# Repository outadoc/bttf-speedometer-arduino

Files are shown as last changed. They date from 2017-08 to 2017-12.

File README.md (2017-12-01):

Arduino-based Back to the Future DeLorean Speedometer
=====================================================

Finished prototype
------------------
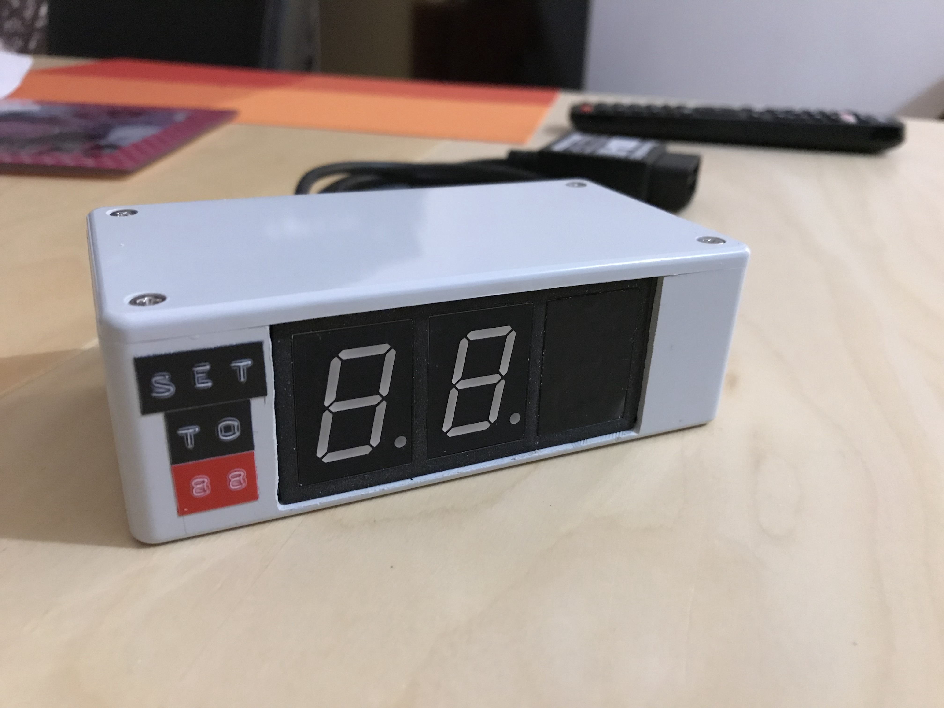
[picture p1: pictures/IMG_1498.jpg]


License
-------
    Copyright (C) 2017  Baptiste Candellier

    This program is free software: you can redistribute it and/or modify
    it under the terms of the GNU General Public License as published by
    the Free Software Foundation, either version 3 of the License, or
    (at your option) any later version.

    This program is distributed in the hope that it will be useful,
    but WITHOUT ANY WARRANTY; without even the implied warranty of
    MERCHANTABILITY or FITNESS FOR A PARTICULAR PURPOSE.  See the
    GNU General Public License for more details.

    You should have received a copy of the GNU General Public License
    along with this program.  If not, see <https://www.gnu.org/licenses/>.

Components
----------

| Part | Qty  | Manufacturer | Reference |
|---|---|---|---|
| OBD-II UART Adapter V2 | x1 | Freematics | OBD-U |
| Microcontroller | x1 | Arduino | Arduino Nano |
| Enclosure | x1 | Hammond | 1591C |
| 7-segment display | x3 | Multicomp | LS0803SRWK |
| Potentiometer | x1 | Vishay | 3296W-1-203LF |
| Slide switch | x1 | C&K | OS102011MA1QN1 |
| Slide switch | x1 | Knitter-Switch | MFS131D |
| Resistor (165 Ω) | x8 | Vishay | MRS25000C1650FCT00 |
| 16-pin board-to-board conn. | x2 | AMP | 6-534237-4 |
| DB25 male connector | x1 | FCI | DB25S064TLF |
| DB25 female connector + shell | x1 | MH | MHDTPPK-25 | 
| 10-pin wire-to-board housing  | x1 | Molex | 22-01-2105 |
| 5-pin wire-to-board housing | x1 | Molex | 22-01-2055 |
| 10-pin wire-to-board header | x1 | Molex | 22-27-2101 |
| 5-pin wire-to-board header | x1 | Molex | 22-27-2051 |
| Crimp terminal | many | Molex | 0008500113 |
| Labels | x3 | Dymo | Omega |

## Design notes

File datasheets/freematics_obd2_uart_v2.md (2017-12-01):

# Freematics OBD-II UART Adapter V2 (for Arduino)

This product works as a data bridge between a car's OBD-II port and Arduino with dedicated Arduino library provided. It provides fast OBD-II data access, as well as 6-axis MEMS motion sensor module and voltmeter for measuring car battery voltage. The adapter draws power from OBD-II port and convert it to 5V (up to 2.1A) for powering itself and attached device (Arduino board, shield or other components). 

## Features

- Access to all standard OBD-II PIDs with extended ELM327 AT command-set
- Reading and clearing vehicle diagnostic trouble codes (engine & powertrain only)
- Measuring car battery voltage
- Built-in MPU-6050 6-DOF motion sensor (accelerometer, gyroscope & temperature)
- Supplying power for host device (5V up to 2.1A)
- Serial UART data interface compatible with both 3.3V and 5V micro-controllers
- Micro USB port for computer/tablet OBD-II access and firmware upgrade
- Arduino library and example sketches available
- Low power mode @6mA

## Compatibility

The adapter plugs into the OBD port usually located under the steering column or slightly to the left of it. To check if your vehicle is OBD-II certified, open your hood and find the sticker that looks like this:

Vehicles using following vehicle protocols are supported.

- CAN 500Kbps/29bit
- CAN 500Kbps/11bit
- CAN 250Kbps/29bit
- CAN 250Kbps/11bit
- KWP2000 Fast
- KWP2000 5Kbps
- ISO9141-2

The OBD-II Adapter is compatible with all Arduino range including Arduino UNO, Arduino Leonardo, Arduino Micro, Arduino Nano, Arduino Mini, Arduino Pro Mini, Arduino MEGA 1280/2560/ADK.

## Connectors

The adapter stays plugged into the OBD port usually located under the steering column or slightly to the left of it.  A cable comes out from the adapter and splits into one 4-pin connector two 2-pin connectors, including power lines (VCC/GND) and data lines (Rx/Tx). They can be connected to Arduino with onboard breakout pins or breakout shield. Your Arduino device will look tidy in car with only one cable.

Power Connector (2-pin 2.54 Dupont connector)

- Red: VCC (connecting to Arduino’s VCC)
- Black: GND (connecting to Arduino’s GND)

Serial UART Data Connector (2-pin 2.54 Dupont connector)

- White: Rx (connected to Arduino’s serial Tx)
- Green: Tx (connected to Arduino’s serial Rx)

USB Port

- For connection with computer or tablet via micro USB cable
- For power output (5V/2A)

## Extended ELM327 Command Set

We have extended standard ELM327 command set for following purposes:

- Multiple (up to 8) OBD-II PIDs reading from a single query
- Accessing built-in MEMS module (MPU-6050)
- Accessing built-in voltmeter (measuring battery voltage)

Following are the added commands:

### ATACL

- Function: reading accelerometer data
- Response: X/Y/Z values from accelerometer in format of X,Y,Z

### ATGYRO

- Function: reading gyroscope data
- Response: X/Y/Z values in the format X,Y,Z

### ATTEMP

- Function: reading temperature data
- Response: temperature (raw) data

### ATRV

- Function: reading car battery voltage
- Response: voltage value

The Arduino library has API implemented with all the extended commands.

## Library

A dedicated Arduino library is provided for easy access to all the features with any type of Arduino.

Some commonly used APIs are like following:

- setBaudRate - set adapter serial baudrate
- readPID - read specified OBD-II PID and return parsed value
- clearDTC - clear diagnostic trouble code
- getVoltage - measure car battery voltage
- getVIN - retrieve Vehicle Identification Number
- getTemperature - get device temperature
- readAccel - read accelerometer X/Y/Z values
- readGyro - read gyroscope X/Y/Z values

There are more extensive APIs experts. Please refer to the library header file for more information.

Here is an example Arduino sketch of a simplest engine RPM indicator, which uses the pin 13 LED (built in on Arduino board) to indicate whether the engine is above 3000 rpm.

```cpp
#include <OBD2UART.h>

COBD obd;

void setup()
{
  // we'll use the debug LED as output
  pinMode(13, OUTPUT);
  // start communication with OBD-II adapter
  obd.begin();
  // initiate OBD-II connection until success
  while (!obd.init());
}

void loop()
{
  int value;
  // save engine RPM in variable 'value', return true on success
  if (obd.readPID(PID_RPM, value)) {
    // light on LED on Arduino board when the RPM exceeds 3000
    digitalWrite(13, value > 3000 ? HIGH : LOW);
  }
}
```

A more comprehensive example sketch can be found here.

Some commonly used PIDs are defined in OBD library as following.

### Engine

- PID_RPM – Engine RPM (rpm)
- PID_ENGINE_LOAD – Calculated engine load (%)
- PID_COOLANT_TEMP – Engine coolant temperature (°C)
- PID_ENGINE_LOAD – Calculated Engine load (%)
- PID_ABSOLUTE_ENGINE_LOAD – Absolute Engine load (%)
- PID_TIMING_ADVANCE – Ignition timing advance (°)
- PID_ENGINE_OIL_TEMP – Engine oil temperature (°C)
- PID_ENGINE_TORQUE_PERCENTAGE – Engine torque percentage (%)
- PID_ENGINE_REF_TORQUE – Engine reference torque (Nm)

### Intake/Exhaust

- PID_INTAKE_TEMP – Intake temperature (°C)
- PID_INTAKE_PRESSURE – Intake manifold absolute pressure (kPa)
- PID_MAF_FLOW – MAF flow pressure (grams/s)
- PID_BAROMETRIC – Barometric pressure (kPa)

### Speed/Time

- PID_SPEED – Vehicle speed (km/h)
- PID_RUNTIME – Engine running time (second)
- PID_DISTANCE – Vehicle running distance (km)

### Driver

- PID_THROTTLE – Throttle position (%)
- PID_AMBIENT_TEMP – Ambient temperature (°C)

### Electric Systems

- PID_CONTROL_MODULE_VOLTAGE – vehicle control module voltage (V)
- PID_HYBRID_BATTERY_PERCENTAGE – Hybrid battery pack remaining life (%)

Additional defines can be added to access all OBD-II PIDs which the car’s ECU provides.

## Comparison

The following table lists the differences among different Freematics OBD-II adapter models.

| Features \ Models | OBD-II I2C Adapter | OBD-II UART Adapter V1 | OBD-II UART Adapter V2 |
|---|---|---|---|
| Connection Interface | I2C | Serial UART | Serial UART |
| Additional Interface | N/A | N/A | microUSB |
| MEMS Sensor | MPU-6050 | N/A | MPU-6050 |
| Voltmeter | Yes | Yes | Yes |
| Max. Output Power | 2A | 2A | 2.1A |
| Standby Mode Power | 10mA | 5mA | 6mA |

## FAQ

**Q:** What is this product used for?  
**A:** The most straight-forward use of this product is for making Arduino possible to access vehicle data easily. The OBD-II data, together with other data from GPS or all kinds sensors, can be logged and stored on SD/TF card with Arduino and that makes an open-source vehicle data logger (check out the data logger kits). More extensively, many interesting interaction applications requiring car data can be made.

**Q:** How is the adapter powered?  
**A:** The adapter gets power from the 12V DC output from the OBD-II port.

**Q:** Does my Arduino needs power from somewhere in the car?  
**A:** The adapter provides regulated 5V output for powering Arduino and other devices, so no extra power cord is needed.

**Q:** Do I need a CAN bus shield to use with the adapter?  
**A:** Definitely no. The adapter retrieves data from CAN bus, like a CAN bus shield does and convert the more complicated CAN bus interface to simple serial UART interface which Arduino and most embedded systems are easy to access. The data connection is provided by adapter’s data connector (Rx and Tx).

**Q:** How do I connect the adapter with my Arduino?  
**A:** The adapter works with all models of Arduino with the dedicated Arduino library and is connected with Arduino by connecting adapter’s Tx to Arduino’s Rx (D0) and adapter’s Rx to Arduino’s Tx (D1). If you want to connect and disconnect the adapter with your Arduino effortlessly, it’s recommended to use a common I/O breakout shield or use an Arduino board with breakout pins for Rx/Tx/VCC/GND.

**Q:** Is the power provided by the adapter always available in car?  
**A:** This depends on whether the OBD-II port of your car still has power after ignition is off. Actually it is so with most cars.

**Q:** What’s the maximum frequency of data polling?  
**A:** The OBD-II PIDs are polled one after another. The time for a polling depends on the speed of car’s ECU computer and how busy the computer is in different status. With a typical modern car with CAN bus, the time can be as low as 10ms. In other word, up to 100 times of data polling can be done in one second.

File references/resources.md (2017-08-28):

*Mark D* on DMCTalk:

> The digital speedo box is made from Hammond enclosure PN 1591CGY. 

> The original was actually blue so production painted it white. The gray enclosure is close in color that you wouldn't need to paint it or you can still paint it satin white. The connector on the back is a D-sub type connector like you'd find on an old printer cable. There are various types you can buy on Newark.com, mouser.com, etc that are close, I don't have a source for any that are identical to the screen used connector.

> The digital displays were originally made by Stanley Readout and are basically extinct at this point since they're ancient technology. Most people use 7 segment LED displays that look pretty accurate if you put a sheet of acetate film over the displays to act as a diffuser. I made a speedo a long time ago and used 1/16" styrene sheet to build the little black frame around each digit. The black border is part of the Stanley Readout on the real car, but you can make a close approximation of the real thing with polystyrene around an LED display and paint it black.

> Here's a CAD model of how the original was constructed showing the Stanley Readout housings. If you're going for super accuracy people have made plastic castings of the stanley bodies and then made matching circuit boards with grain of wheat size incadecent bulbs or warm LED's. It also requires manufacturing a clear lens and as well. 

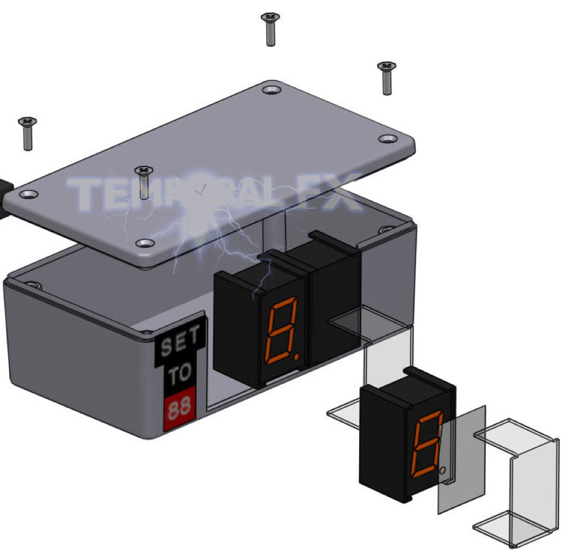
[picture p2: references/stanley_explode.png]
stanley readout model


> The speedo was originally 3 digits and would read XX.X Apparently the third 1/10 MPH digit made reading the display confusing so production put a piece of black gaffer's tape over the 3rd digit so you only see XX. 

> 1. The original box had areas where the paint was scratched through and you could see the blue plastic below. The paint was an off white/light gray color.

> 2. The digits should sit flush with the outside of the case.

> 3. Only a couple of Stanley readout displays have ever been found. The couple that still exist actually came from one of the production crew members that still had them from when the screen used cars were built. The bulbs are incandescent and run hot, so small LEDs are usually a better choice when making replicas. I don't have a ready source available for buying castings of the stanley housings. There is also a clear lens that clips over the black plastic housing that needs to be cast or cut from sheets of clear plastic and glued together. Making a mold for casting is difficult due to the shape and depth of the recesses in the part. The black housings may be a good candidate for 3D printing rather than molding. Creating reproduction circuit boards are also a complicating factor.  
> A simpler solution is to use a readily available 7 segment LED displays and add plastic housings cut from sheet polystyrene to make them look more like the Stanley displays.

> 4. The diffuser is a sheet of matte acetate, can be found at craft stores, amazon, staples, office max, etc.
https://www.amazon.com/Grafix-Acetat...YPMZ64EREHJ18Z

> 5. The TCD labels were originally made with a special type of label maker and required black and red tape that would print white. Finding a vintage label maker and the correct size tape is probably not going to be viable option.  
> A much better solution is to have custom vinyl decals printed and then cut them out to size. The Month, Day, Year, Hour, Min labels are .218" tall, the Destination Time, Present Time and Last Time Departed labels are .281" tall, and the AM PM labels are .188 tall. The labels were originally trimmed by hand to fit and are not all perfectly square or exactly the same height. The font is Microgramma Bold Extended

> 6. The digital speedo was originally built with three digits and would have read 88.0 when the car hits 88 mph. This presumably proved to be difficult to read on screen and looked like "880" so production covered the tenths digit with a piece of black gaffer's tape.
https://www.amazon.com/3M-Cloth-Gaff.../dp/B00H95LOIG

> The actual machine is a Kroy Model 80 label printer. It's 80's tech that's long since become obsolete so finding a working machine and the special printing tape in the right colors is an expensive (and time consuming) way to go. You also have to find the correct font printing wheel. A much better option is to print on vinyl and cut to size.

[Source thread][dmc-talk-thread]

[stanley-explode]: stanley_explode.png
[dmc-talk-thread]: http://dmctalk.org/showthread.php?11228-BTTF-Time-Machine-Build-Questions-Ask-Me-Anything&highlight=labels

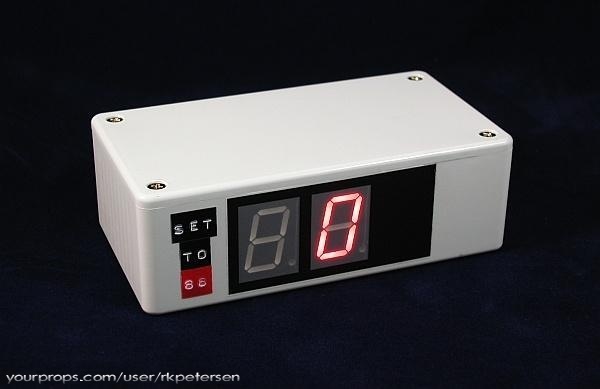
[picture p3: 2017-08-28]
references/gps_prop_2.jpg

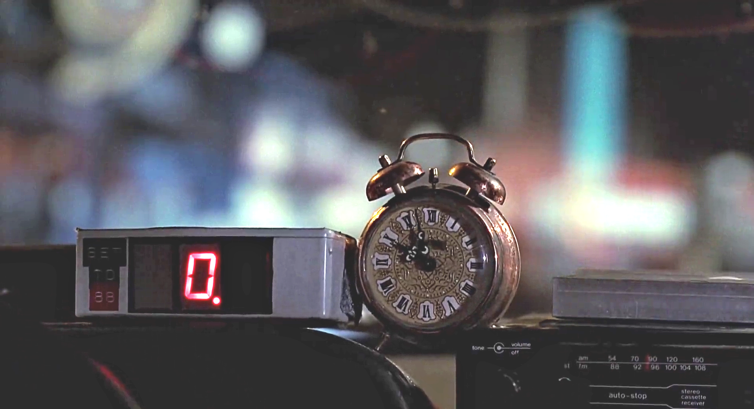
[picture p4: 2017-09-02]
references/bttf1_screen_0_front.png

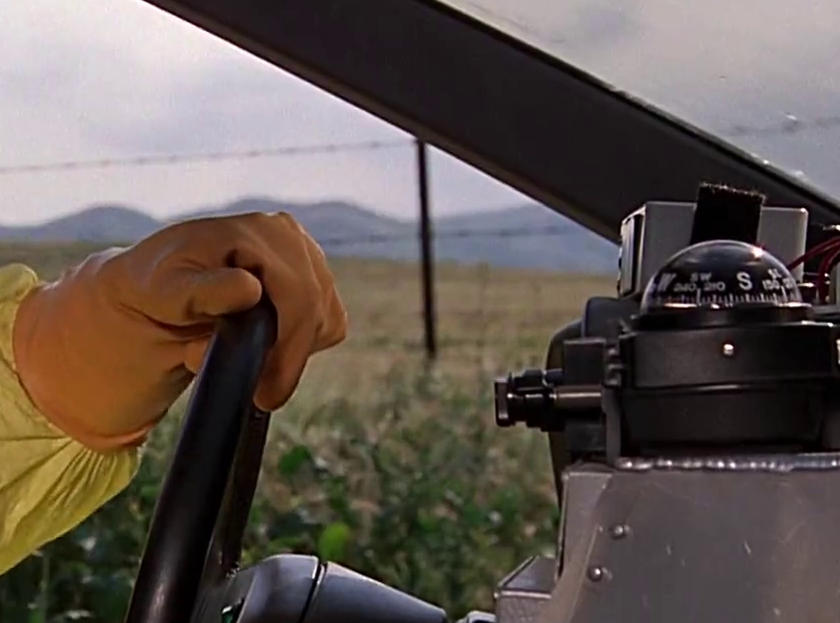
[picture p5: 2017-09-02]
references/bttf1_side.png

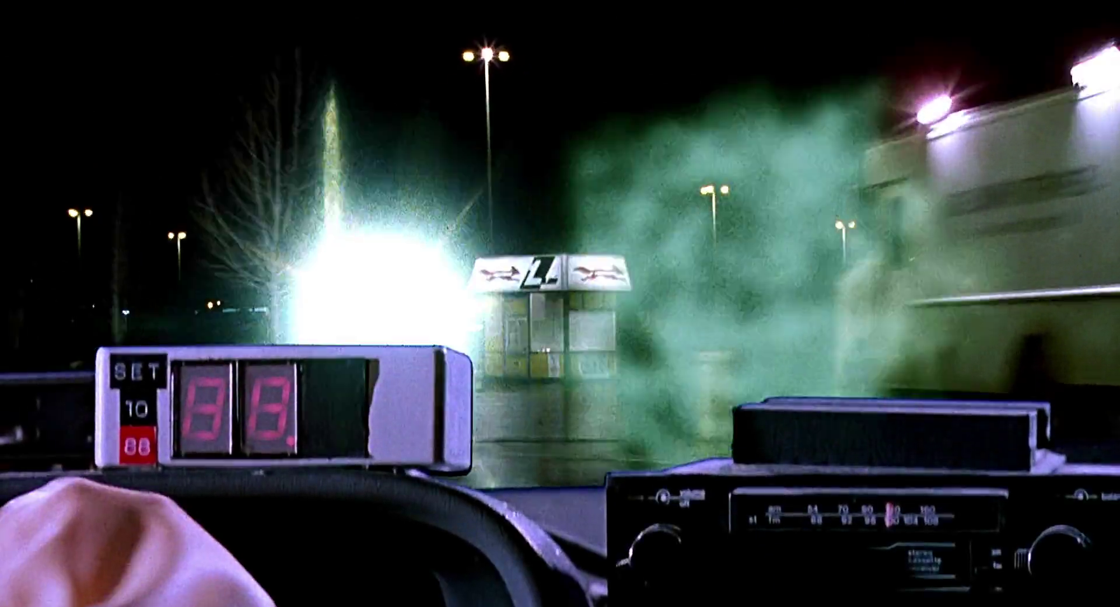
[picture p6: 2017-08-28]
references/bttf1_screen_88_front.png

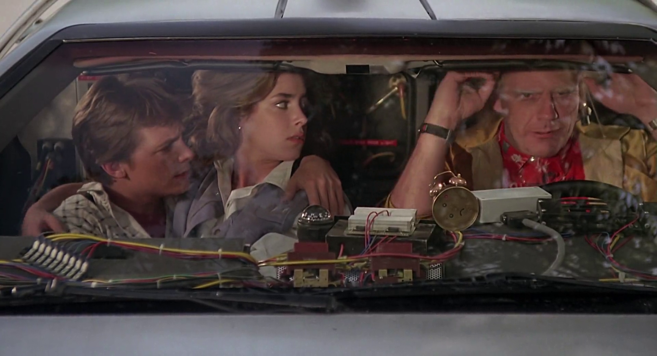
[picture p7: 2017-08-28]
references/bttf1_screen_back.png

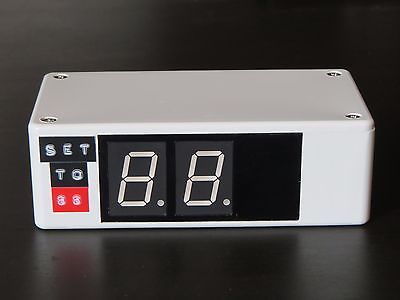
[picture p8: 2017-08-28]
references/gps_prop_1.jpg

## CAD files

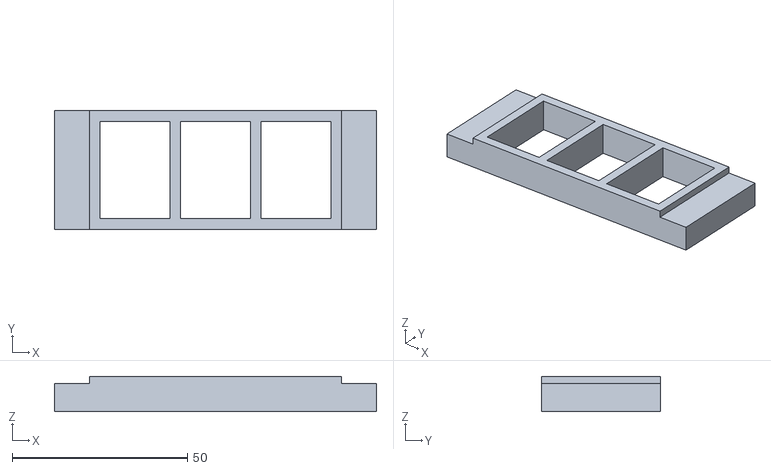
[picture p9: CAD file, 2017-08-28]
cad/bttf_speedo_digit_frame.stl
92.0 x 34.0 x 10.1

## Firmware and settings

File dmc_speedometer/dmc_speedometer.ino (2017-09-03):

#include <avr/sleep.h>
#include <TimerOne.h>
#include <MsTimer2.h>
#include <OBD2UART.h>
#include <SevSeg.h>
#include <Narcoleptic.h>

#define STATE_DISCONNECTED 0x0
#define STATE_CONNECTED    0x2
#define STATE_SLEEPING     0x3

#define TIMER_INTERVAL_DISP_REFRESH_MS 10
#define TIMER_INTERVAL_DISP_INC_MS   500

#define PIN_SEG_A  5
#define PIN_SEG_B  6
#define PIN_SEG_C  7
#define PIN_SEG_D  8
#define PIN_SEG_E  9
#define PIN_SEG_F  10
#define PIN_SEG_G  11
#define PIN_SEG_DP 12

#define PIN_DIG_1 A1
#define PIN_DIG_2 A2

#define PIN_USE_IMPERIAL 2
#define PIN_USE_METRIC 3

#define PIN_SPEED_ADJUST 0

//#define MODE_SIMULATION

typedef uint8_t speed_t;
typedef uint8_t state_t;

SevSeg sevseg;
COBD obd;

volatile state_t state;
volatile speed_t target_read_speed;

float modifier;
volatile bool should_display_imperial;
volatile bool should_display_metric;

void setup() {
    state = STATE_DISCONNECTED;
    target_read_speed = 0;

    pinMode(PIN_USE_IMPERIAL, INPUT);
    pinMode(PIN_USE_METRIC, INPUT);

    // Read speed modifier (1.0 keeps raw speed read from OBD)
    // Play with the potentiometer to adjust to real speed or switch to mph
    modifier = (float)map(analogReadAvg(PIN_SPEED_ADJUST, 20, 20), 
                            0, 1024, 9000, 12000) / (float)10000.0;

    #ifdef MODE_SIMULATION
        Serial.begin(9600);
        Serial.println(modifier, 4);
    #endif

    setup_display();
    setup_timers();
    setup_interrupts();

    // Initialize display unit
    isr_read_display_unit();
}

void setup_timers() {
    Timer1.initialize(TIMER_INTERVAL_DISP_REFRESH_MS * 1000);
    Timer1.attachInterrupt(isr_refresh_display);

    MsTimer2::set(TIMER_INTERVAL_DISP_INC_MS, isr_display);
    MsTimer2::start();
}

void setup_interrupts() {
    // When switching kph/OFF/mph, update the switch states in memory 
    attachInterrupt(digitalPinToInterrupt(PIN_USE_IMPERIAL), isr_read_display_unit, CHANGE);
    attachInterrupt(digitalPinToInterrupt(PIN_USE_METRIC), isr_read_display_unit, CHANGE);
}

void setup_display() {
    byte numDigits = 2;
    byte digitPins[] = {PIN_DIG_1, PIN_DIG_2};
    byte segmentPins[] = {
        PIN_SEG_A,
        PIN_SEG_B,
        PIN_SEG_C,
        PIN_SEG_D,
        PIN_SEG_E,
        PIN_SEG_F,
        PIN_SEG_G,
        PIN_SEG_DP
    };
    bool resistorsOnSegments = true;
    byte hardwareConfig = COMMON_CATHODE;
    bool updateWithDelays = false;
    bool leadingZeros = false;
    
    sevseg.begin(hardwareConfig, numDigits, digitPins, segmentPins, 
        resistorsOnSegments, updateWithDelays, leadingZeros);
    
    sevseg.blankWithDp();
}

void setup_obd_connection() {
    sevseg.blankWithDp();
#ifndef MODE_SIMULATION
    obd.begin();

    // initialize OBD-II adapter
    for (;;) {
        int value;
        // Try to init and read speed; if we can't do either of them, sleep for a while
        if (obd.init() && obd.readPID(PID_SPEED, value)) {
            // Connection established!
            break;            
        }

        state = STATE_DISCONNECTED;
        
        // Enter deep sleep; disable all timers, serial comm., interrupts, etc.
        sevseg.blankWithDp();
        obd.enterLowPowerMode();
        Narcoleptic.delay(8000);
        obd.leaveLowPowerMode();
    }
#else
    delay(1000);
#endif

    state = STATE_CONNECTED;
}

void loop() {
    noInterrupts();
    state_t loc_state = state;
    interrupts();
    
    if (loc_state == STATE_DISCONNECTED) {
        // Clear display if we couldn't read the speed, and try reconnecting
        setup_obd_connection();
    }

    if (loc_state == STATE_SLEEPING) {
        enter_sleep_mode();
        return;
    }

    probe_current_speed();
}

// INTERRUPTS

void isr_display() {
    // Speed currently displayed; will be incremented to reach target speed
    static speed_t curr_disp_speed = 0;
    
    if (state != STATE_CONNECTED) {
        return;        
    }
    
    // Make copy of target speed
    const speed_t target_speed = adjust_speed(target_read_speed);

    // We want to increment speed one by one until we hit the target speed
    // on a relatively short duration
    double interval_between_incs = TIMER_INTERVAL_DISP_INC_MS / (abs(target_speed - curr_disp_speed));

    // Enable interrupts for the rest of the procedure,
    // because we want the display to still be refreshed
    interrupts();

    if (curr_disp_speed == target_speed) {
        set_displayed_speed(curr_disp_speed);        
    }

    // Until we've hit the target speed, increment, display and pause
    while (curr_disp_speed != target_speed) {
        if (curr_disp_speed < target_speed) {
            curr_disp_speed++;
        } else {
            curr_disp_speed--;
        }
        
        // Display and pause execution for a fixed amount of time between each iteration
        set_displayed_speed(curr_disp_speed);
        delay(interval_between_incs);
    }
}

// Called every 10 ms
void isr_refresh_display() {
    sevseg.refreshDisplay();
}

void isr_read_display_unit() {
    // If we were sleeping, wake up
    if (state == STATE_SLEEPING) {
        leave_sleep_mode();
        state = STATE_DISCONNECTED;
    }

    // Read display mode from switch
    should_display_imperial = digitalRead(PIN_USE_IMPERIAL);
    should_display_metric = digitalRead(PIN_USE_METRIC);

    if (!should_display_imperial && !should_display_metric) {
        state = STATE_SLEEPING;
        sevseg.blank();
    }
}

speed_t adjust_speed(speed_t speed) {
    // Adjust read speed using modifier (set via potentiometer) and take
    // unit into account
    if (should_display_imperial) {
        // Convert from km/h to mph
        return round(modifier * (float)speed * 0.621371);
    }
    
    return round(modifier * (float)speed);
}

void set_displayed_speed(speed_t speed) {
    // Display number with a decimal point
    sevseg.setNumber(speed, 0);
}

void probe_current_speed() {
    if (state != STATE_CONNECTED)
        return;

#ifndef MODE_SIMULATION
    int value;
    if (obd.readPID(PID_SPEED, value)) {
        noInterrupts();
        target_read_speed = value;
        interrupts();
        return;
    }

    noInterrupts();
    state = STATE_DISCONNECTED;
    target_read_speed = 0;
    interrupts();
#else
    delay(50);
    
    noInterrupts();
    target_read_speed = (millis() / 1000 * 5) % 145;
    interrupts();
#endif
}

int analogReadAvg(const int sensorPin, const int numberOfSamples, const long timeGap) {
    static int currentSample;
    static int currentValue = 0;

    for (int i = 0; i < numberOfSamples; i++) {
        currentSample = analogRead(sensorPin);
        currentValue += currentSample;
        delay(timeGap);
    }

    return (currentValue / numberOfSamples);
}

void enter_sleep_mode() {
#ifndef MODE_SIMULATION
    obd.enterLowPowerMode();
#endif
    set_sleep_mode(SLEEP_MODE_PWR_DOWN);
    noInterrupts(); // make sure we don't get interrupted before we sleep
    sleep_enable(); // enables the sleep bit in the mcucr register
    interrupts();   // interrupts allowed now, next instruction WILL be executed
    sleep_cpu();    // here the device is put to sleep
}

void leave_sleep_mode() {
    sleep_disable();
#ifndef MODE_SIMULATION
    obd.leaveLowPowerMode();
#endif
}

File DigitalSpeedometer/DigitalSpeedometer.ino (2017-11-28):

/* Arduino-based replica of the Back to the Future DeLorean Speedometer
   Copyright (C) 2017  Baptiste Candellier

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
   You should have received a copy of the GNU General Public License
   along with this program.  If not, see <https://www.gnu.org/licenses/>.  */

#include <Arduino.h>

#include <avr/sleep.h>
#include <TimerOne.h>
#include <MsTimer2.h>
#include <OBD2UART.h>
#include <SevSeg.h>
#include <Narcoleptic.h>

#include "DigitalSpeedometer.h"

SevSeg sevseg;

#ifndef MODE_SIMULATION
COBD obd;
#endif

volatile state_t state;
volatile speed_t target_read_speed;

volatile float modifier;
volatile int unit_select;

void setup() {
    state = STATE_DISCONNECTED;
    target_read_speed = 0;

    pinMode(PIN_UNIT_SELECT, INPUT_PULLUP);
    pinMode(PIN_SLEEP_ENABLE, INPUT_PULLUP);

    // Read speed modifier (1.0 keeps raw speed read from OBD)
    // OBD speed can be a bit different from real life speed, so play with 
    // the potentiometer to adjust to real speed
    modifier = (float)map(analog_read_avg(PIN_SPEED_ADJUST, 20, 20), 
                            0, 1024, 9000, 12000) / (float)10000.0;

    #ifdef MODE_SIMULATION
        Serial.begin(9600);
        Serial.println(modifier, 4);
    #endif

    setup_display();
    setup_timers();
    setup_interrupts();

    // Initialize display unit switch and sleep mode interrupts
    isr_check_display_unit();
    isr_check_sleep_mode();
}

void loop() {
    noInterrupts();
    isr_check_sleep_mode();
    state_t loc_state = state;
    interrupts();

    // Yay, finite state machine!
    switch (loc_state) {
        case STATE_DISCONNECTED:
            // If we got disconnected (or on first loop), try reconnecting
            setup_obd_connection();
            break;        
        case STATE_SLEEPING:
            // If we switched the switch to OFF, time for sleepies
            enter_sleep_mode();
            break;
        case STATE_CONNECTED:
            // We should be connected. PROBE!
            probe_current_speed();
            break;
    }
}

void enter_sleep_mode() {
    noInterrupts();

    // Blank the display and wait a little before sleeping
    sevseg.blank();
    delay(500);

#ifndef MODE_SIMULATION
    if (state == STATE_CONNECTED) {
        obd.enterLowPowerMode();
    }
#endif

    set_sleep_mode(SLEEP_MODE_PWR_DOWN);
    sleep_enable(); // enables the sleep bit in the mcucr register
    interrupts();   // interrupts allowed now, next instruction WILL be executed
    sleep_cpu();    // here the device is put to sleep
}

void leave_sleep_mode() {
    // Wakey wakey, eggs and bakey
    sleep_disable();
    
    noInterrupts();
    state = STATE_DISCONNECTED;
    interrupts();
}

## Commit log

2017-08-12 Attempt some Timer1 shennanigans (stuck on zero until we move, then blank)
    [dmc_speedometer.ino]
2017-08-14 Improve potentiometer precision and round modifier to prevent jittering
    [dmc_speedometer.ino]
2017-08-18 Fix build by actually starting the freaking timer
    Add a finer debug level for interruptions
    [dmc_speedometer.ino]
2017-08-19 Better project structure, commit datasheets and models
    [bttf_speedo_digit_frame.stl]
2017-08-20 Yet another attempt at fixing shit
    [dmc_speedometer.ino]
2017-08-27 Swap around OBD reading and display interpolation
    [dmc_speedometer.ino]
2017-08-28 Improve interrupts
2017-08-28 Add pin constants
2017-08-30 Support switch from km/h to mph; go to sleep state if neither is selected
    Improve potentiometer accuracy, kinda
2017-09-01 Disable interrupts before reading state, use typedef
2017-09-01 Blank screen correctly before sleep
    [dmc_speedometer.ino]
2017-09-03 Attempt fix for return from sleep mode
    Check if we're disconnected *or* sleeping before running OBD and
    display code
    [dmc_speedometer.ino]
2017-09-03 Add arduino.json
2017-11-05 Change hardware configuration: 1 switch for sleep mode, 1 for unit select + clean up some of the code
2017-11-23 Enable pull-up resistors for slide switches
2017-11-27 Improve readability while trying to fix sleep mode
    Try to send obd.enterLowPowerMode only if we could connect to the adapter
    [DigitalSpeedometer.h, DigitalSpeedometer.ino]
2017-12-01 Add board-to-board connector
